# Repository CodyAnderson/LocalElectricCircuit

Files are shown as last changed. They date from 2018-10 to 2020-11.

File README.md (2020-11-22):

# LocalElectricCircuit

This is the repository containing the Circuit board files for the Global Electric Circuit project.

Other Global Electric Circuit project repositories can be found at:

| Repository | Description |
|:--- |:---  |
| [GlobalCircuit](https://github.com/chordtoll/GlobalCircuit) | PIC32 code |
| [GECaux](https://github.com/chordtoll/GECaux) | PIC16 code |
| [GECutils](https://github.com/chordtoll/GECutils) | Python scripts |
| [LocalElectricCircuit](https://github.com/CodyAnderson/LocalElectricCircuit)| Circuit board files |

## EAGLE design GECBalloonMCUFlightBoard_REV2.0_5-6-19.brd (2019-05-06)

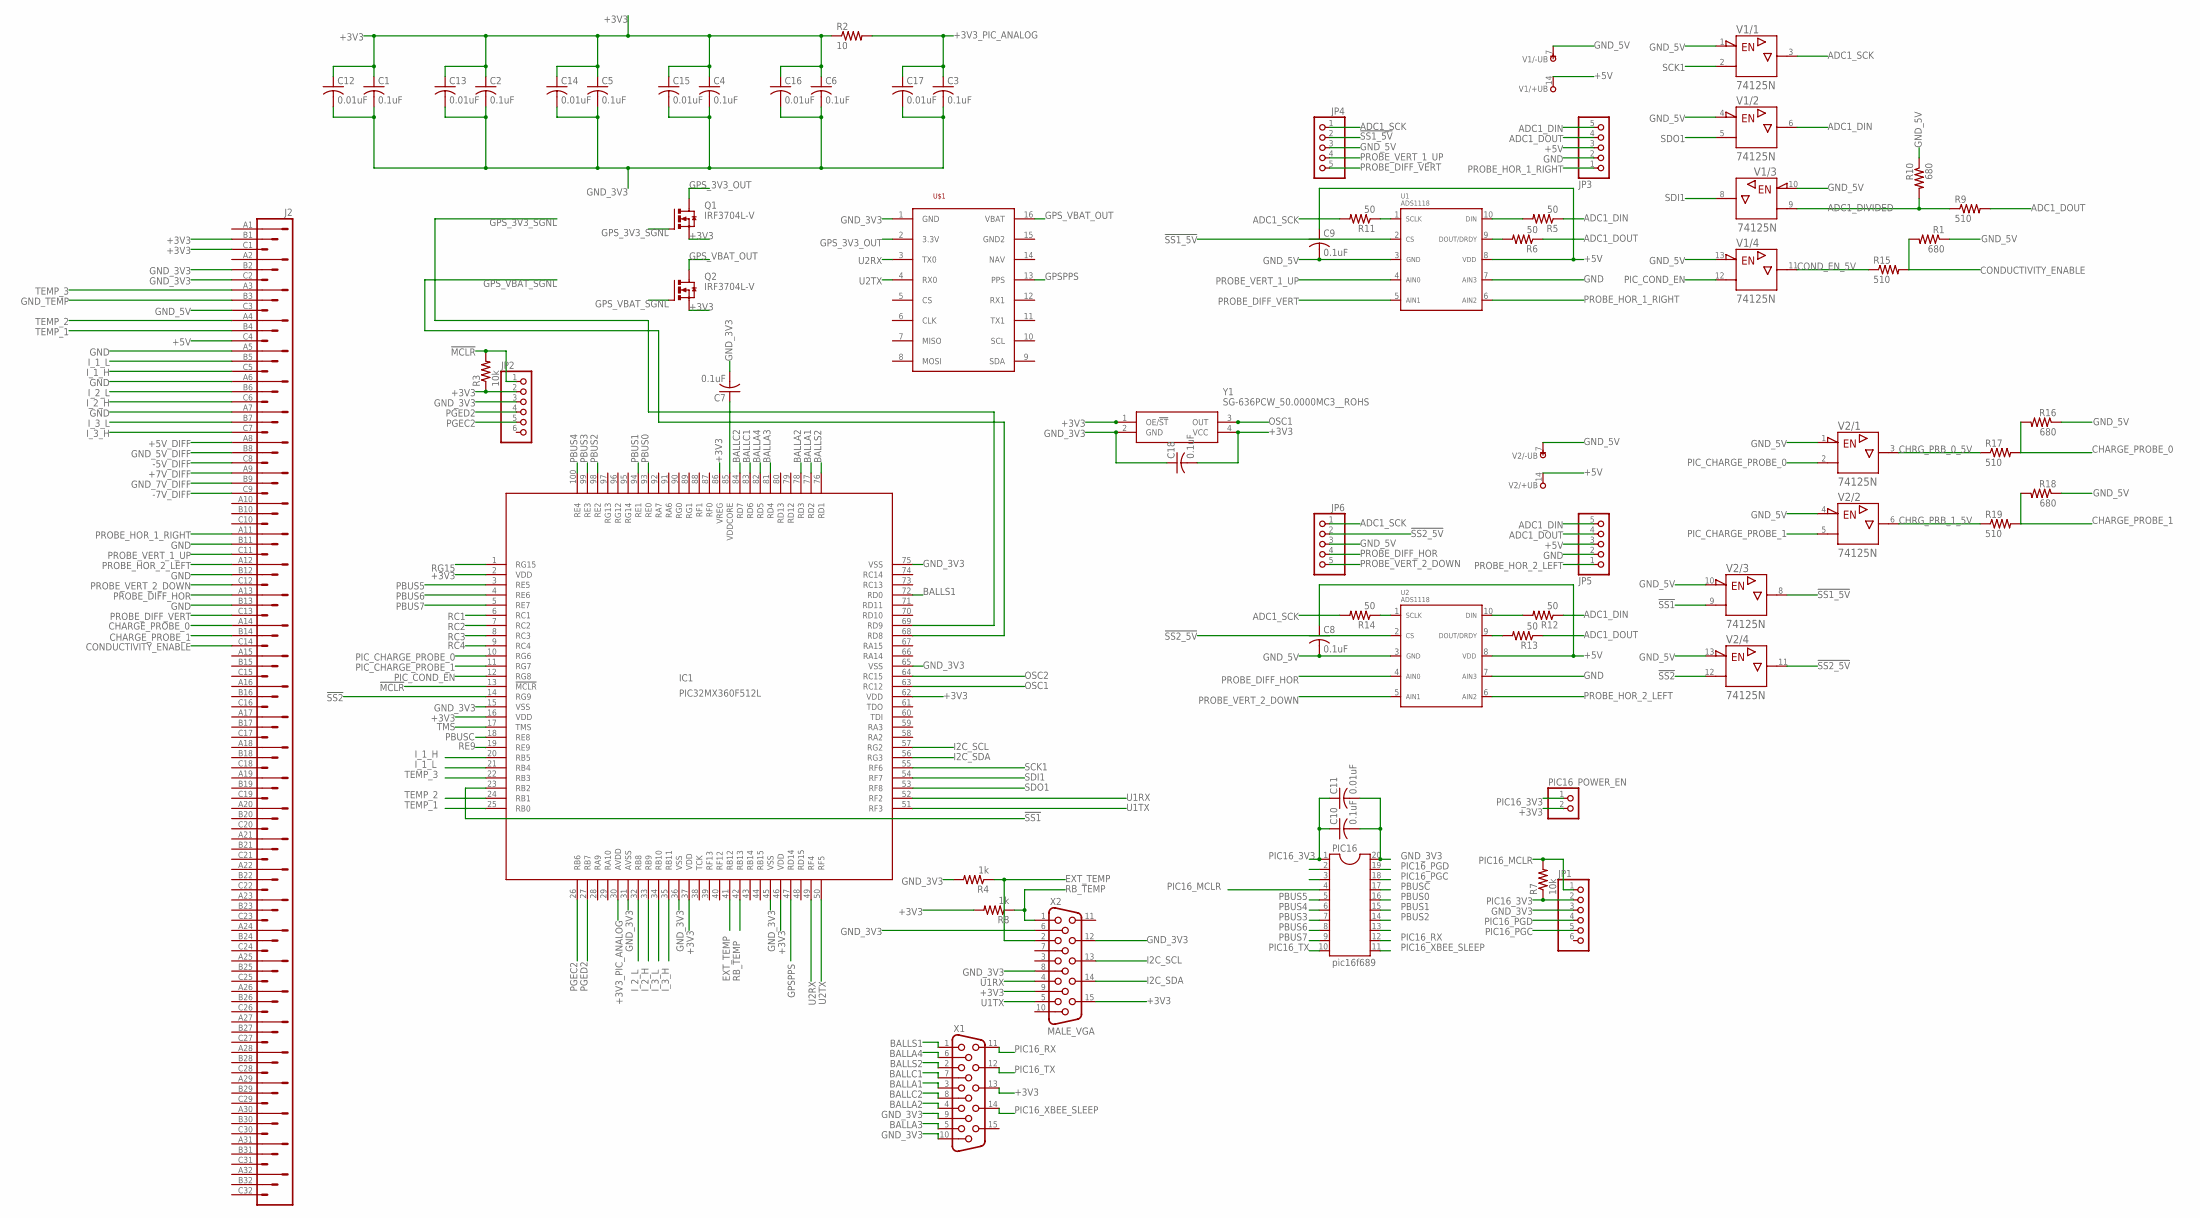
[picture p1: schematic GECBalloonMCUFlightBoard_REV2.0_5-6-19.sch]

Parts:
C1, C2, C3, C4, C5, C6, C7, C8, C9, C10, C18: 0.1uF; C1206
C11, C12, C13, C14, C15, C16, C17: 0.01uF; C1206
IC1: PIC32MX360F512L; TQFP100
J2: VG96KB
JP1, JP2: PINHD-1X6; 1X06
JP3, JP4, JP5, JP6: PINHD-1X5; 1X05
PIC16: pic16f689; DIL20
PIC16_POWER_EN: PINHD-1X2; 1X02
Q1, Q2: IRF3704L-V; TO262-V
R1, R10, R16, R18: 680; R1206
R2: 10; M1206
R3, R7: 10k; M1206
R4, R8: 1k; 0414/15
R5, R6, R11, R12, R13, R14: 50; M1206
R9, R15, R17, R19: 510; R1206
U1, U2: ADS1118; MSOP10
U$1: SPARKFUN_VENUS_GPS_BREAKOUT; SPARKFUN_BOARD
V1, V2: 74125N; DIL14
X1: HF15H; HDF15H
X2: MALE_VGA; MALE_PACKAGE
Y1: SG-636PCW_50.0000MC3__ROHS; SG-636

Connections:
!MCLR: IC1.13 (!MCLR), JP2.1, R3.2
!SS1: IC1.23 (RB2), V2.9 (A)
!SS1_5V: JP4.2, U1.2 (CS), V2.8 (Y)
!SS2: IC1.14 (RG9), V2.12 (A)
!SS2_5V: JP6.2, U2.2 (CS), V2.11 (Y)
+3V3: C1.1, C2.1, C4.1, C5.1, C6.1, C12.1, C13.1, C14.1, C15.1, C16.1, C18.2, IC1.2 (VDD), IC1.16 (VDD), IC1.37 (VDD), IC1.46 (VDD), IC1.62 (VDD), IC1.86 (VREG), J2.B1, J2.C1, JP2.2, PIC16_POWER_EN.2, Q1.3 (S), Q2.3 (S), R2.1, R3.1, R8.2, X1.13, X2.9, X2.15, Y1.1 (OE/!ST), Y1.4 (VCC)
+3V3_PIC_ANALOG: C3.1, C17.1, IC1.30 (AVDD), R2.2
+5V: C8.1, C9.1, J2.C4, JP3.3, JP5.3, U1.8 (VDD), U2.8 (VDD), V1.14 (+UB), V2.14 (+UB)
+5V_DIFF: J2.A8
+7V_DIFF: J2.A9
-5V_DIFF: J2.C8
-7V_DIFF: J2.C9
ADC1_DIN: JP3.5, JP5.5, R5.1, R12.1, V1.6 (Y)
ADC1_DIVIDED: R9.1, R10.2, V1.9 (A)
ADC1_DOUT: JP3.4, JP5.4, R6.1, R9.2, R13.1
ADC1_SCK: JP4.1, JP6.1, R11.2, R14.2, V1.3 (Y)
BALLA1: IC1.77 (RD2), X1.3
BALLA2: IC1.78 (RD3), X1.4
BALLA3: IC1.81 (RD4), X1.5
BALLA4: IC1.82 (RD5), X1.6
BALLC1: IC1.83 (RD6), X1.7
BALLC2: IC1.84 (RD7), X1.8
BALLS1: IC1.72 (RD0), X1.1
BALLS2: IC1.76 (RD1), X1.2
CHARGE_PROBE_0: J2.A14, R16.2, R17.2
CHARGE_PROBE_1: J2.B14, R18.2, R19.2
CHRG_PRB_0_5V: R17.1, V2.3 (Y)
CHRG_PRB_1_5V: R19.1, V2.6 (Y)
CONDUCTIVITY_ENABLE: J2.C14, R1.2, R15.2
COND_EN_5V: R15.1, V1.11 (Y)
EXT_TEMP: IC1.41 (RB12), R4.1, X2.2
GND: J2.A5, J2.A6, J2.A7, J2.B11, J2.B12, J2.B13, JP3.2, JP5.2, U1.7 (AIN3), U2.7 (AIN3)
GND_3V3: C1.2, C2.2, C3.2, C4.2, C5.2, C6.2, C7.2, C10.2, C11.2, C12.2, C13.2, C14.2, C15.2, C16.2, C17.2, C18.1, IC1.15 (VSS), IC1.31 (AVSS), IC1.36 (VSS), IC1.45 (VSS), IC1.65 (VSS), IC1.75 (VSS), J2.B2, J2.C2, JP1.3, JP2.3, PIC16.20, R4.2, U$1.1 (GND), X1.9, X1.10, X2.6, X2.8, X2.12, Y1.2 (GND)
GND_5V: C8.2, C9.2, J2.C3, JP4.3, JP6.3, R1.1, R10.1, R16.1, R18.1, U1.3 (GND), U2.3 (GND), V1.1 (!G), V1.4 (!G), V1.7 (-UB), V1.10 (!G), V1.13 (!G), V2.1 (!G), V2.4 (!G), V2.7 (-UB), V2.10 (!G), V2.13 (!G)
GND_5V_DIFF: J2.B8
GND_7V_DIFF: J2.B9
GND_TEMP: J2.B3
GPSPPS: IC1.47 (RD14), U$1.13 (PPS)
GPS_3V3_OUT: Q1.2 (D), U$1.2 (3.3V)
GPS_3V3_SGNL: IC1.69 (RD9), Q1.1 (G)
GPS_VBAT_OUT: Q2.2 (D), U$1.16 (VBAT)
GPS_VBAT_SGNL: IC1.68 (RD8), Q2.1 (G)
I2C_SCL: IC1.57 (RG2), X2.13
I2C_SDA: IC1.56 (RG3), X2.14
I_1_H: IC1.20 (RB5), J2.C5
I_1_L: IC1.21 (RB4), J2.B5
I_2_H: IC1.33 (RB9), J2.C6
I_2_L: IC1.32 (RB8), J2.B6
I_3_H: IC1.35 (RB11), J2.C7
I_3_L: IC1.34 (RB10), J2.B7
unnamed: R5.2, U1.10 (DIN)
unnamed: R6.2, U1.9 (DOUT/DRDY)
unnamed: R11.1, U1.1 (SCLK)
unnamed: R12.2, U2.10 (DIN)
unnamed: R13.2, U2.9 (DOUT/DRDY)
unnamed: R14.1, U2.1 (SCLK)
OSC1: IC1.63 (RC12), Y1.3 (OUT)
OSC2: IC1.64 (RC15)
PBUS0: IC1.93 (RE0), PIC16.16
PBUS1: IC1.94 (RE1), PIC16.15
PBUS2: IC1.98 (RE2), PIC16.14
PBUS3: IC1.99 (RE3), PIC16.7
PBUS4: IC1.100 (RE4), PIC16.6
PBUS5: IC1.3 (RE5), PIC16.5
PBUS6: IC1.4 (RE6), PIC16.8
PBUS7: IC1.5 (RE7), PIC16.9
PBUSC: IC1.18 (RE8), PIC16.17
PGEC2: IC1.26 (RB6), JP2.5
PGED2: IC1.27 (RB7), JP2.4
PIC16_3V3: C10.1, C11.1, JP1.2, PIC16.1, PIC16_POWER_EN.1, R7.1
PIC16_MCLR: JP1.1, PIC16.4, R7.2
PIC16_PGC: JP1.5, PIC16.18
PIC16_PGD: JP1.4, PIC16.19
PIC16_RX: PIC16.12, X1.11
PIC16_TX: PIC16.10, X1.12
PIC16_XBEE_SLEEP: PIC16.11, X1.14
PIC_CHARGE_PROBE_0: IC1.10 (RG6), V2.2 (A)
PIC_CHARGE_PROBE_1: IC1.11 (RG7), V2.5 (A)
PIC_COND_EN: IC1.12 (RG8), V1.12 (A)
PROBE_DIFF_HOR: J2.A13, JP6.4, U2.4 (AIN0)
PROBE_DIFF_VERT: J2.C13, JP4.5, U1.5 (AIN1)
PROBE_HOR_1_RIGHT: J2.A11, JP3.1, U1.6 (AIN2)
PROBE_HOR_2_LEFT: J2.A12, JP5.1, U2.6 (AIN2)
PROBE_VERT_1_UP: J2.C11, JP4.4, U1.4 (AIN0)
PROBE_VERT_2_DOWN: J2.C12, JP6.5, U2.5 (AIN1)
RB_TEMP: IC1.42 (RB13), R8.1, X2.1
RC1: IC1.6 (RC1)
RC2: IC1.7 (RC2)
RC3: IC1.8 (RC3)
RC4: IC1.9 (RC4)
RE9: IC1.19 (RE9)
RG15: IC1.1 (RG15)
SCK1: IC1.55 (RF6), V1.2 (A)
SDI1: IC1.54 (RF7), V1.8 (Y)
SDO1: IC1.53 (RF8), V1.5 (A)
TEMP_1: IC1.25 (RB0), J2.B4
TEMP_2: IC1.24 (RB1), J2.A4
TEMP_3: IC1.22 (RB3), J2.A3
TMS: IC1.17 (TMS)
U1RX: IC1.52 (RF2), X2.4
U1TX: IC1.51 (RF3), X2.5
U2RX: IC1.49 (RF4), U$1.3 (TX0)
U2TX: IC1.50 (RF5), U$1.4 (RX0)
VCAP/VCORE: C7.1, IC1.85 (VDDCORE)

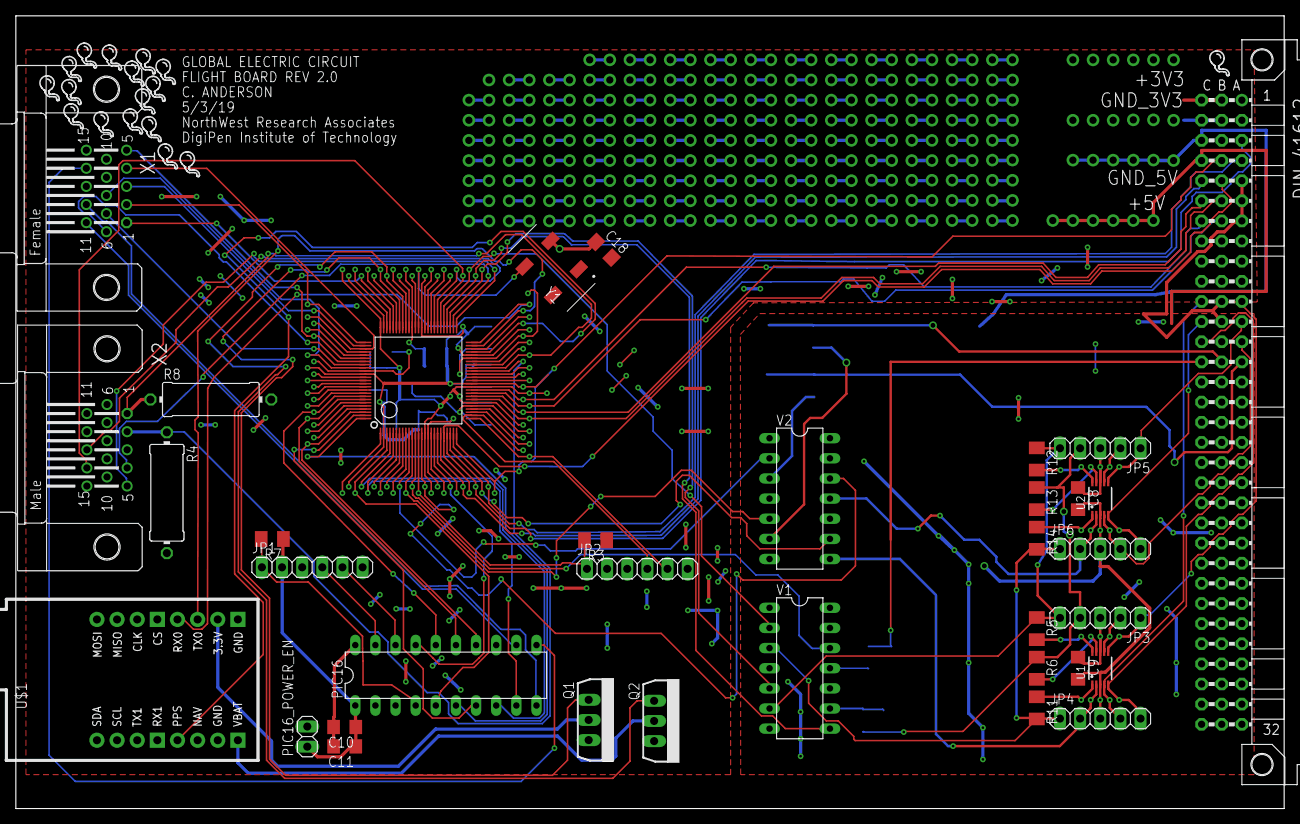
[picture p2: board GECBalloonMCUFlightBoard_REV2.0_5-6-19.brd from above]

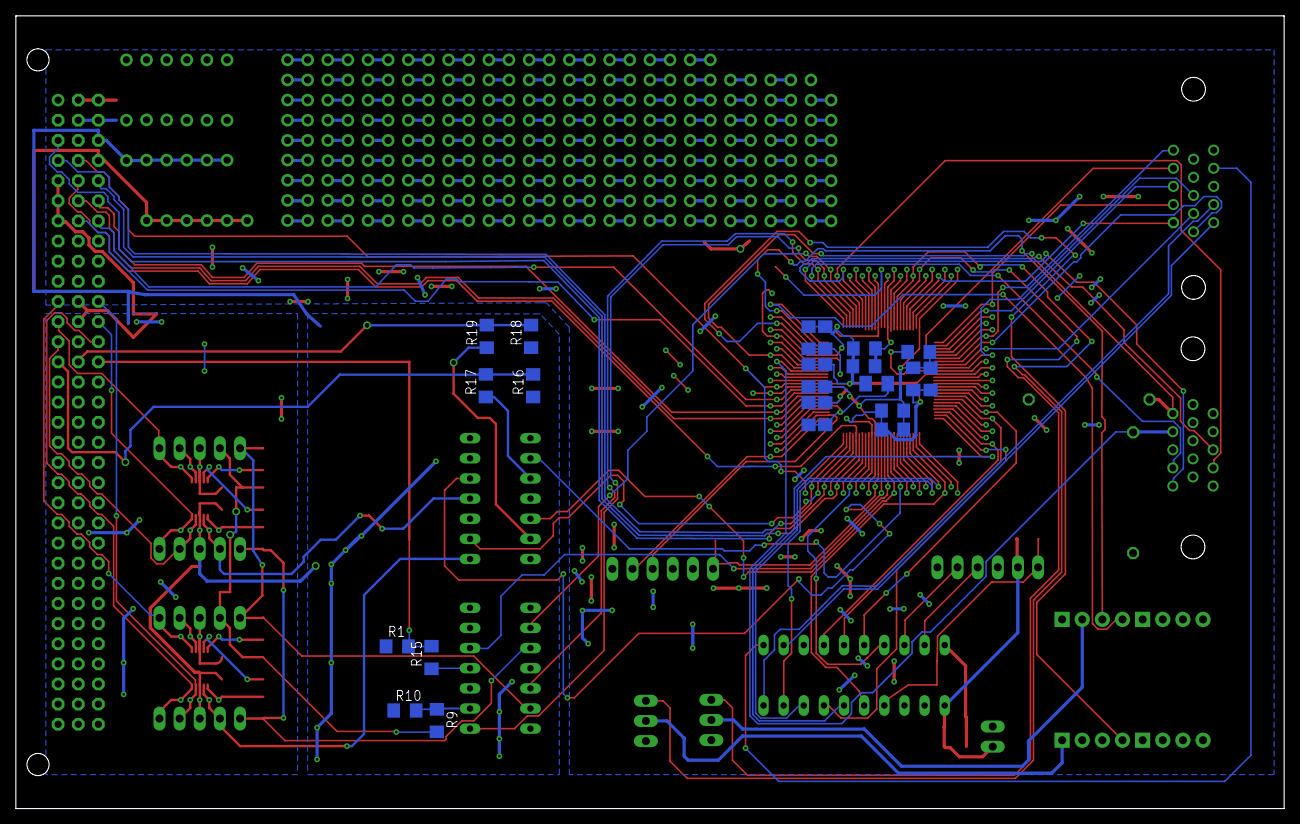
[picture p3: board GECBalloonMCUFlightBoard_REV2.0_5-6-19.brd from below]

Board: 2 copper layers, 160.0 x 100.0 mm, 74 parts (22 on the bottom side), 89 nets.

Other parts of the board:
U$2, U$3, U$4, U$5, U$6, U$7, U$8, U$9, U$10, U$11, U$12, U$14, U$15, U$16, U$17, U$19, U$21: BALLOON

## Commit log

2018-08-08 Here it is, worlsd
    [LocalElectricCircuit.brd, LocalElectricCircuit.sch]
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2018-08-08 Connected PIC32 analog pins
    [LocalElectricCircuit.brd, LocalElectricCircuit.sch]
2018-08-08 Ballast pins added
    [LocalElectricCircuit.brd]
2018-08-08 Added conductivity pins
    [LocalElectricCircuit.brd]
2018-08-08 Added I2C labels
    [LocalElectricCircuit.brd]
2018-08-08 Well, I hope this got it all in there 😭
    [LocalElectricCircuit.sch]
2018-08-08 aware of dog pleas pet dog
    [LocalElectricCircuit.brd, LocalElectricCircuit.sch]
2018-08-08 Oh boy o"bertor
    [LocalElectricCircuit.brd, LocalElectricCircuit.sch]
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2018-08-08 Transistor circuit updated to be active high and to save power.
    [LocalElectricCircuit.brd, LocalElectricCircuit.sch]
2018-08-08 ADDED ADC RESISTORS DONT KNOW HOW TO USE GITHUB IM SORRY IN ADVANCE
    [LocalElectricCircuit.brd, LocalElectricCircuit.sch]
2018-08-08 CHANGED NAMES OF THE NETS LOTS OF TORNADOS COMING SOON NOW WE CAN PROGARM
    [LocalElectricCircuit.brd, LocalElectricCircuit.sch]
2018-08-09 THIS HERE PIC32 COULD JUST NOT LEARN ANYTHING NEW UNTIL NETS RENAMED WERE TWO
    [LocalElectricCircuit.brd, LocalElectricCircuit.sch]
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2018-08-09 GND planes and some layout bizz
    [LocalElectricCircuit.brd, LocalElectricCircuit.sch]
2018-08-09 It's a healthy baby board!
    [LocalElectricCircuit.brd, LocalElectricCircuit.sch]
2018-08-09 ✋✋✋✋✋hol' up hol' up ✋✋ looks 👀 like we got a master 🎓 memer 🐸🐸🐸 over here 👈👈👈
    [LocalElectricCircuit.brd, LocalElectricCircuit.sch]
2018-08-09 According to all known laws of aviation, there is no way a 🅱 should be able to fly.
    [LocalElectricCircuit.brd]
2018-08-09 gO gO POWER RANGERS
    [LocalElectricCircuit.brd]
2018-08-09 Fixed a whole ton of issues from DRC Figured out there were vias stacked on eachother which caused 'Drill Distance' error Figured out that the radius around vias was set smaller than the general gap 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
    [LocalElectricCircuit.brd, LocalElectricCircuit.sch]
2018-08-09 Wired some air and stopped some t's an 🅱's
    [LocalElectricCircuit.brd]
2018-08-09 LETTERS ON SILK SCREEN COVERING PADS ON FEILDS OF GREEN THREE BOYZ MISS MEETING
    [LocalElectricCircuit.brd]
2018-08-09 Added board name and credits and whatnot
    [LocalElectricCircuit.brd]
2018-08-09 So far I've only ripped up a trace to have something to commit for the new branch
    [LocalElectricCircuit.brd]
2018-08-10 Fan out step numero uno
    [LocalElectricCircuit.brd, LocalElectricCircuit.sch]
2018-08-10 I'm a FAN of this pinout 😁 Am I right, laides 😉
    [LocalElectricCircuit.brd]
2018-08-10 Auto router did a goody
    [LocalElectricCircuit.brd]
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2018-08-10 Minor DRC fixes.
    [LocalElectricCircuit.brd]
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2018-08-13 Added Male VGA part
    [LocalElectricCircuit.brd, LocalElectricCircuit.sch]
2018-08-13 male VGA connector has been auto-routed
    [LocalElectricCircuit.brd, LocalElectricCircuit.sch]
2018-08-15 Fixed planes, resistor collision
    [LocalElectricCircuit.brd]
2018-08-21 Update silk screen with REv 1.0 and date Added fan out for all PIC pins Began on fan out for ADC pins ETC.
    [LocalElectricCircuit.brd, LocalElectricCircuit.sch]
2018-08-21 Did a whole ton of stuff. Added the level-shifting hardware Added fan out for ADC's Worked on clearing some DRC errors ETC
    [LocalElectricCircuit.brd, LocalElectricCircuit.sch]
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2018-08-22 Actually pre auto routing
    [LocalElectricCircuit.brd]
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2018-08-22 VIAS STOOD ALONE FIELDS OF CIRCLES, MILLIMETERS BETWEEN COPY PASTA RIPPY UPPY DONE
    [LocalElectricCircuit.brd, LocalElectricCircuit.sch]
2018-08-22 Fixing problems
    [LocalElectricCircuit.brd, LocalElectricCircuit.sch]
2018-08-22 Renamed the files to contain the Revision number in them. Also deleted a bunch of useless backup files and also renamed the rendered .pdfs to have more descriptive names.
    [LocalElectricCircuit.sch, LocalElectricCircuit_REV1.0_8-22-18.brd, LocalElectricCircuit_REV1.0_8-22-18.sch]
2018-08-23 THIS IS THE VERSION OF THE BOARD SENT TO BE MADE
    [LocalElectricCircuit_REV1.0_8-22-18.brd]
2018-08-23 Renamed files for a more professional look
    [GECBalloonMCUFlightBoard_REV1.0_8-22-18.brd, GECBalloonMCUFlightBoard_REV1.0_8-22-18.sch]
2018-10-12 First attempt at making a direct-to-board mount for the wiring harness type of connector.
    [TestVGAHack.brd]
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2018-10-12 Two VGA's at the same time
    [StackHack.brd, TestVGAHack.brd, TestVGAHack_NO_VIAS.brd]
2018-10-27 Updated VGA hack board
    [TestVGAHack.brd]
2018-10-27 Updated VGA hcak board more Should now have spots for I2C and UART connections
    [TestVGAHack.brd]
2018-11-19 Various changes to the board. With this, the testing setup has been functional for quite a while...
    [TestOscillatorBoard.brd, TestVGAHack.brd]
2018-11-19 COnnected GPSPPS pin and Incremented revision number
    [GECBalloonMCUFlightBoard_REV2.0_11-19-18.brd, GECBalloonMCUFlightBoard_REV2.0_11-19-18.sch]
2018-11-24 Swapped out oscillator for external crystal clock and connected GND and 3V3 planes better.
    [GECBalloonMCUFlightBoard_REV1.0_8-22-18.brd, GECBalloonMCUFlightBoard_REV1.0_8-22-18.sch, GECBalloonMCUFlightBoard_REV2.0_11-23-18.brd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]
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2019-05-03 Added PIC16_XBEE_SLEEP pin to the VGA connector X1 on PIN14
    [GECBalloonMCUFlightBoard_REV2.0_11-23-18.brd, GECBalloonMCUFlightBoard_REV2.0_11-23-18.sch]
2019-05-04 Added GPS power mosfet and GPS standby mosfet.
    [GECBalloonMCUFlightBoard_REV2.0_11-23-18.brd, GECBalloonMCUFlightBoard_REV2.0_11-23-18.sch]
2019-05-06 So far, manage to rip up old traces without totally losing the PIC32's fan out
    [GECBalloonMCUFlightBoard_REV2.0_11-23-18.brd, GECBalloonMCUFlightBoard_REV2.0_11-23-18.sch]
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2019-05-06 Routed a lot of signals, fixed a lot of errors and nearly lost my mind. Everything on my checklist is complete now, though.
    [GECBalloonMCUFlightBoard_REV2.0_11-23-18.brd, GECBalloonMCUFlightBoard_REV2.0_11-23-18.sch]
2019-05-06 Renamed the board file with an appropriately dated name and generated some pdfs for Jeremy to look at.
    [GECBalloonMCUFlightBoard_REV2.0_5-6-19.brd, GECBalloonMCUFlightBoard_REV2.0_5-6-19.sch]
